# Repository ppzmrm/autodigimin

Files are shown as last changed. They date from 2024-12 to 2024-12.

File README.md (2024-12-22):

# autodigimin
My Digital Theremin Project

Here is the code and wiring diagram for the digital theremin project, now with built-in autotune.  

The required parts are an ESP32 development board to generate tones and generally control things, two HC-SR04+ low-voltage ultrasonic sensors to determine positions of hands to define tone and volume, a X9C103S digital potentiometer to control volume, a Sparkfun TPA2005D1 amplifier to make things audible without trying to draw too much current from a signal pin, and an 8 ohm speaker to play the tones. (Note that to get the volume control on the amplifier to work, you have to remove a solder joint from it, as set out <A HREF=https://www.sparkfun.com/tutorials/392#volume>here</A>. I also ended up snipping off the overhang on one end of the digital potentiometer circuit board, to get it to fit within the width of the breadboard.)

The sources for the libraries used to make it work are in the comments in <A href="autodigimin.ino">the code</a>.

The wiring diagram is as follows:

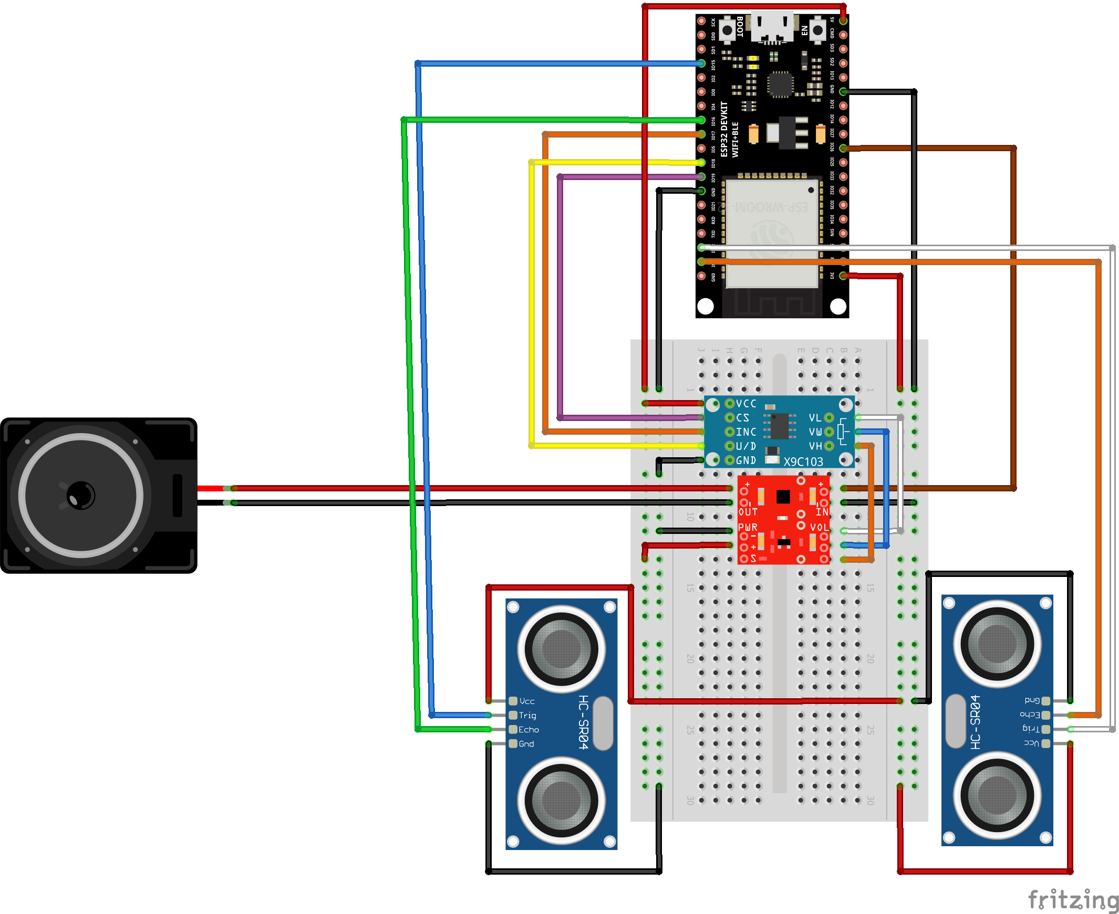
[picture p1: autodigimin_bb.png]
Wiring Diagram


(Note that there are two voltage buses in this breadboard layout: 5v down the left to power amplifier and potentiometer, and 3.3v down the right to power the two ultrasonic sensors, so that their outputs are of the low voltage that the ESP32 requires)

The finished article should look a bit like this (note the snipped-off left-hand end of the digital potentiometer circuit board):

Photo of the finished product

And sound a bit <A href="IMG_1182%201.mov">like this</a>

Note that the <A href="miniautodigimin.ino">most up-to-date version of the code in this repository</a>, which includes a more efficient form of autotuning and defaults to two octaves, has been rejigged a little to use an ESP32 mini, so I can fit the whole thing on a small circuit board.  This required a few I/O pin allocations to be changed, to make use of the ones available on the ESP32 Mini I was using -- code is commented to make clear what the new allocations are.

mini version

Now I just need to put the whole thing in a box!

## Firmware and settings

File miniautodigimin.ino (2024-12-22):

// Digital Theremin project, now with more efficient autouning of notes, and a default tow two octaves in C Major (though other possibilities are included in comments)
// Note that this version has been rejigged a little to use an ESP32 Mini, so some of the IO pins have been changed compared to the original version in the wiring diagram.
// The comments should make clear what the new pin assignments are, and how they change the ultimate wiring.
//
// Have fun!
//
// Michael Merrifield

// Includes libraries for tone generation, pitch definitions, distance sensors, and digital potentiometers
//https://github.com/bhall66/DacTone
#include <DacTone.h>
#include <pitches.h>
//https://github.com/Segilmez06/DistanceSensor
#include <DistanceSensor.h>
//https://github.com/minhaj6/DigiPotX9Cxxx
#include <DigiPotX9Cxxx.h>

// Pin definitions for the tone and volume ultrasonic sensors
#define toneTrigPin 21
#define toneEchoPin 22
#define volTrigPin 16
#define volEchoPin 17        

// Pin definitions for the digital potentiometer (DigiPot)
#define incPin 18
#define udPin 19
#define csPin 23

// Define maximum distances for hand from sensor (volume control needs less dynamic range)
#define maxDF 50.
#define maxDV 25.

//define number of notes to tune to,  In this case, just an octave
//#define Nnotes 8
// Two octaves:
#define Nnotes 15
// Frequencies of autotuned notes
float fnote[Nnotes];

// Set up ultrasonic distance sensors for tone and volume control
DistanceSensor tonehc(toneTrigPin, toneEchoPin);
DistanceSensor volhc(volTrigPin, volEchoPin);

// Set up digital potentiometer as volume control for amplifier
DigiPot pot(incPin,udPin,csPin);

// Audio outpout instances that uses ESP32's sine wave generator
DacTone audio; 


//initialize a few things
void setup() {


//put digipot in defined state
pot.reset();
pot.set(50);
// don't deafen the neighbours
audio.setVolume(50);
//audio.setVolume(100);



// Set the autotuned notes

// C Major Scale
fnote[0] = NOTE_C5;
fnote[1] = NOTE_D5;
fnote[2] = NOTE_E5;
fnote[3] = NOTE_F5;
fnote[4] = NOTE_G5;
fnote[5] = NOTE_A5;
fnote[6] = NOTE_B5;
fnote[7] = NOTE_C6;
// second octave
fnote[8] = NOTE_D6;
fnote[9] = NOTE_E6;
fnote[10] = NOTE_F6;
fnote[11] = NOTE_G6;
fnote[12] = NOTE_A6;
fnote[13] = NOTE_B6;
fnote[14] = NOTE_C7;

/*
// B Flat Major Scale (for Star Trek Theme!)
fnote[0] = NOTE_AS4;
fnote[1] = NOTE_C5;
fnote[2] = NOTE_D5;
fnote[3] = NOTE_DS5;
fnote[4] = NOTE_F5;
fnote[5] = NOTE_G5;
fnote[6] = NOTE_A5;
fnote[7] = NOTE_AS5;
*/


}

// And on to the main loop
void loop() {
  //current distance of hands from sensors
  float fd, vd;
  // instantaneous values of frequency
  float fnow, vnow;
  int inow;
  // smoothed values for playing
  static float f, v; 
  // variables for figuring out autotune
  float df, fbest;

  // get hand distances from volume and tone control ultrasonic sensors
  fd = tonehc.getCM();
  vd = volhc.getCM();
  
   // make sure we are in range 
  if ((fd > maxDF) || (fd == 0)) fd = maxDF;
  if ((vd > maxDV) || (vd == 0)) vd = maxDV;

  // mapping between hand spacing and frequency/volume
  // now using autotuned notes to define linear hand spacing in frequency
  inow = Nnotes - ((Nnotes*fd/maxDF > Nnotes) ? Nnotes : Nnotes*fd/maxDF);
  fnow = fnote[inow];
  // and logarithmic nature of perceived volume
  vnow = 300. * pow(10., -3*vd/maxDV);

 

  // and introduce a bit of smoothing to the values used, to eliminate glitches and to create that theremin glide
  f = 0.9*f + 0.1*fnow;
  v = 0.8*v + 0.2*vnow;
  // set the volume control on the amplifier
  pot.set(v);
  // and play the tone
  audio.tone(f);
  //pause briefly for applause
  delay(10); 
}

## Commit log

2024-12-10 Add files via upload
    Fritzing file for the circuit
    [autodigimin.fzz]
2024-12-10 Add files via upload
    Image of the circuit
2024-12-10 Add files via upload
    Circuit diagram
2024-12-10 Add files via upload
    Fritzing file
    [autodigimin.fzz]
2024-12-10 Add files via upload
    Wiring Diagram
